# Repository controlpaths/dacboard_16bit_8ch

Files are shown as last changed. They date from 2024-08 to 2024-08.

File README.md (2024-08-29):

# 8CH DAC Board (16 bits)

Many times we need to obtain an analog signal from an embedded system. In these cases we will need a digital to analog converter. This board features two 4 channel digital to analog converters with a resolution of 16 bits. 

The output voltage of the board has a range from -10 volt to 10 volts qith a supply voltage of +-12V.

## Analog output

The DAC used in this board is the [DAC80004](https://www.ti.com/product/es-mx/DAC80004), a 4 channel, 16 bits DAC from Texas Instruments. This DAC is footprint compatible with DAC70004 (14 bits), and DAC60004 (12 bits).

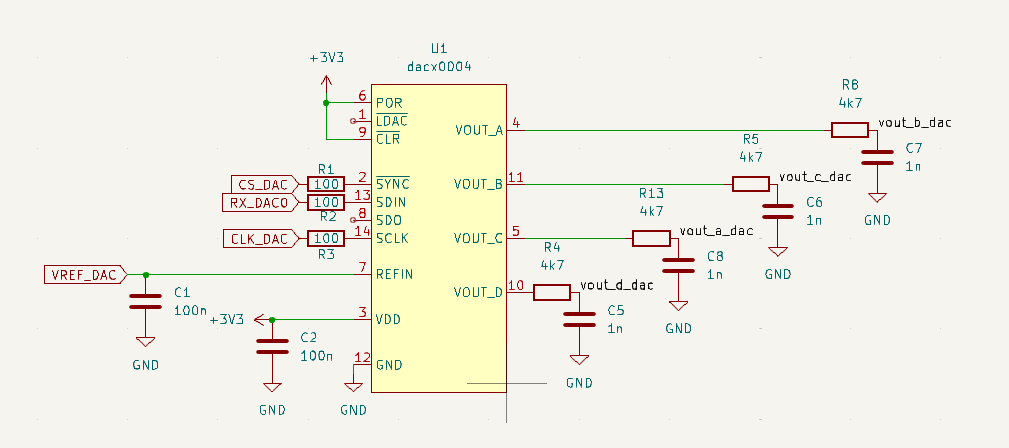
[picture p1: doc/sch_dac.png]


To obtain the bipolar output, a simple circuit with just one amplifier is used. 

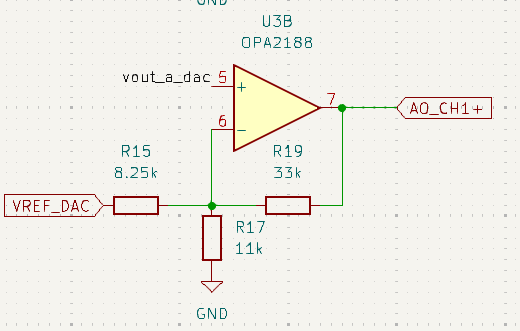
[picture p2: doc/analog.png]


## Voltage reference

For the output range of +-10V, we will need a voltage reference of 2.5 volts. We can reduce the output range, and therefore increase the resolution in volts by using a reference of 1.024 volts or 1.250.

The reference used is the REF5020 with soma capacitors for fixeliminate the noise in the output voltage.

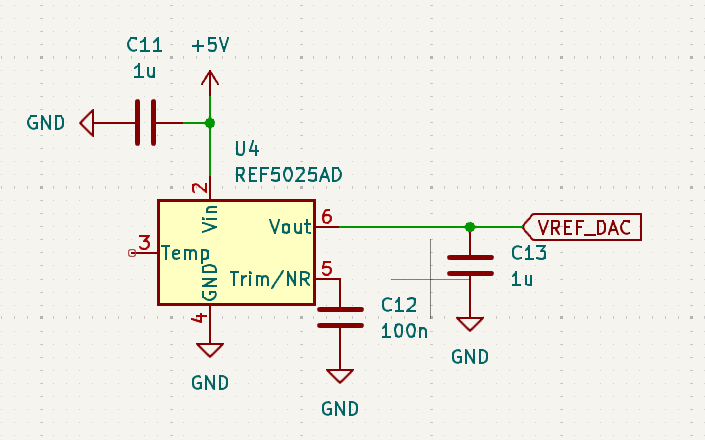
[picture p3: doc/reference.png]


## Connectors

The conenctor are the only component in the bottom side of the board. The board uses three connectors, one for the control of the DAC, and two for the output voltages.

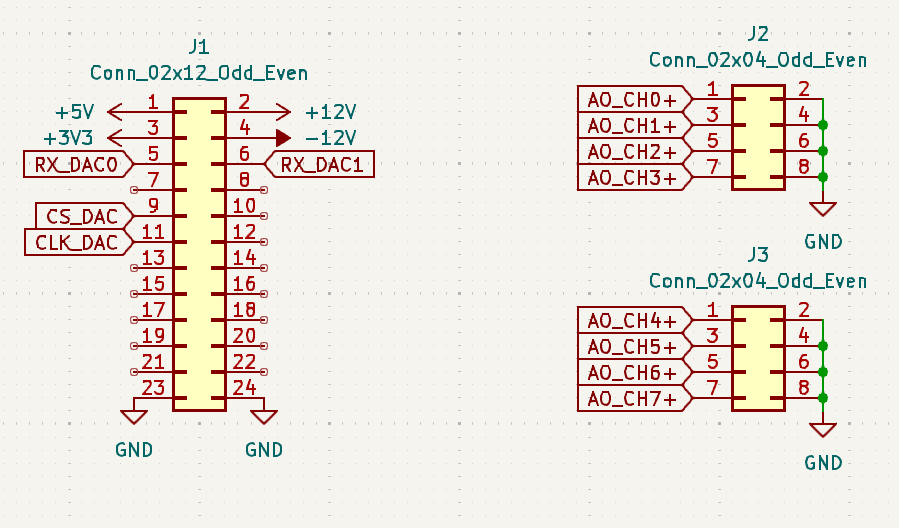
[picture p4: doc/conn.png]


## Layout

The layout of the board is 35mm x 50mm. Several VCC planes and GND planes are used in the board to share the power supplies.

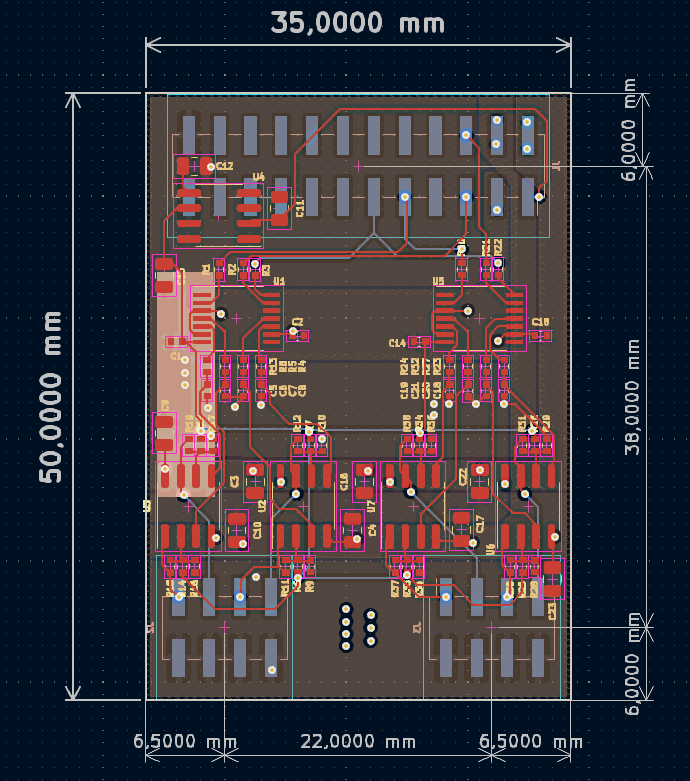
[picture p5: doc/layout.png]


## Get Yours

This DAC Board is open-source, so you can use the output files to build your own in [JLCPCB](https://jlcpcb.com/?from=controlpath). You just need to compress the `gerber` directory, and upload it to [JLCPCB](https://jlcpcb.com/?from=controlpath). 

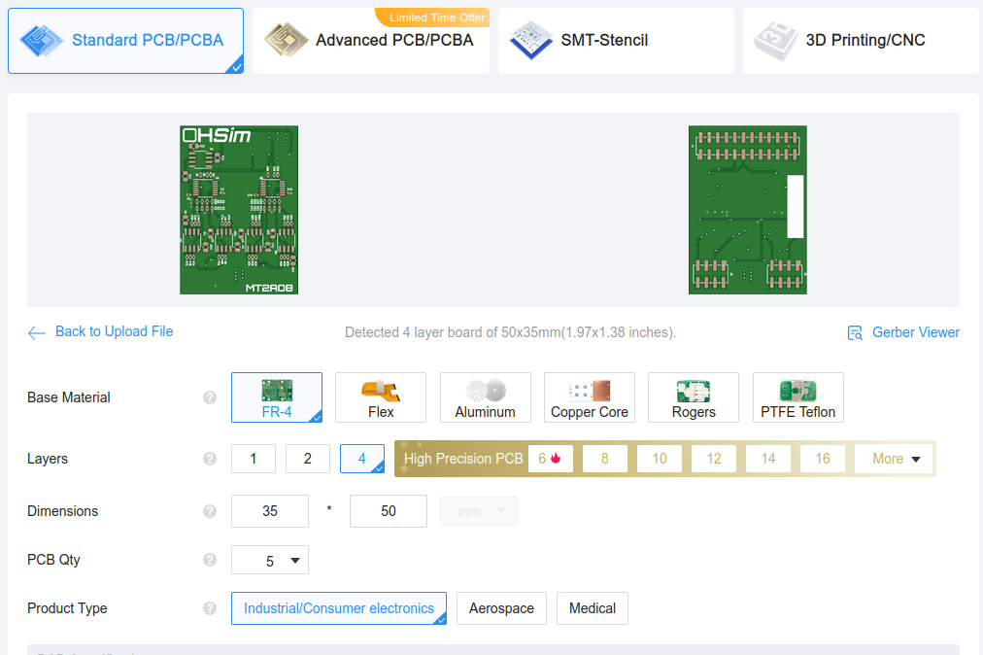
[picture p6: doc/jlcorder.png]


Remember to change the Surface Finish to **LeadFree HASL** to make your board ROHS compliant.

Then you have to add the PCB Assembly service and upload the [centroid](./kicad/production_files/dac16bit_8ch-all-pos.csv) file, and the [BOM](./kicad/production_files/bom.csv).

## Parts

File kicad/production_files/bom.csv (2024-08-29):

Designator | Comment | Footprint | JLCPCB Part #
C1,C2,C14,C15 | 100n | Capacitor_SMD:C_0402_1005Metric
C3,C4,C9,C10,C12,C16,C17,C22,C23 | 100n | Capacitor_SMD:C_0805_2012Metric
C5,C6,C7,C8,C18,C19,C20,C21 | 1n | Capacitor_SMD:C_0402_1005Metric
C11,C13 | 1u | Capacitor_SMD:C_0805_2012Metric
J1 | Conn_02x12_Odd_Even | Connector_PinHeader_2.54mm:PinHeader_2x12_P2.54mm_Vertical_SMD
J2,J3 | Conn_02x04_Odd_Even | Connector_PinHeader_2.54mm:PinHeader_2x04_P2.54mm_Vertical_SMD
R1,R2,R3,R20,R21,R22 | 100 | Resistor_SMD:R_0402_1005Metric
R4,R5,R8,R13,R23,R24,R27,R32 | 4k7 | Resistor_SMD:R_0402_1005Metric
R6,R7,R14,R15,R25,R26,R33,R34 | 8.25k | Resistor_SMD:R_0402_1005Metric
R9,R28 | 11k | Capacitor_SMD:C_0402_1005Metric
R10,R16,R17,R29,R35,R36 | 11k | Resistor_SMD:R_0402_1005Metric
R11,R12,R18,R19,R30,R31,R37,R38 | 33k | Resistor_SMD:R_0402_1005Metric
U1,U5 | dacx0004 | Package_SO:TSSOP-14_4.4x5mm_P0.65mm | C2679895
U2,U3,U6,U7 | OPA2188 | Package_SO:SOIC-8_3.9x4.9mm_P1.27mm | C17271
U4 | REF5025AD | Package_SO:SOIC-8_3.9x4.9mm_P1.27mm

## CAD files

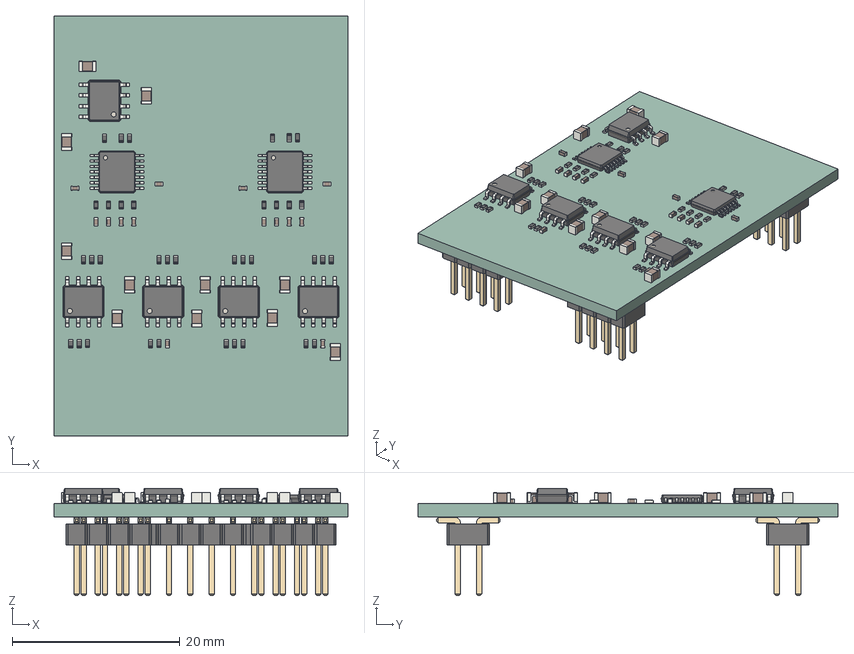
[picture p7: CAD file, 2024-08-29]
kicad/dac16bit_8ch.step
35.0 x 50.0 x 12.8 mm
C_0402_1005Metric x 14
R_0402_1005Metric x 36
C_0805_2012Metric x 11
SOIC_8_39x49mm_P127mm x 5
TSSOP_14_44x5mm_P065mm x 2
PinHeader_2x04_P254mm_Vertical_SMD x 2
PinHeader_2x12_P254mm_Vertical_SMD
MT2AO8_PCB

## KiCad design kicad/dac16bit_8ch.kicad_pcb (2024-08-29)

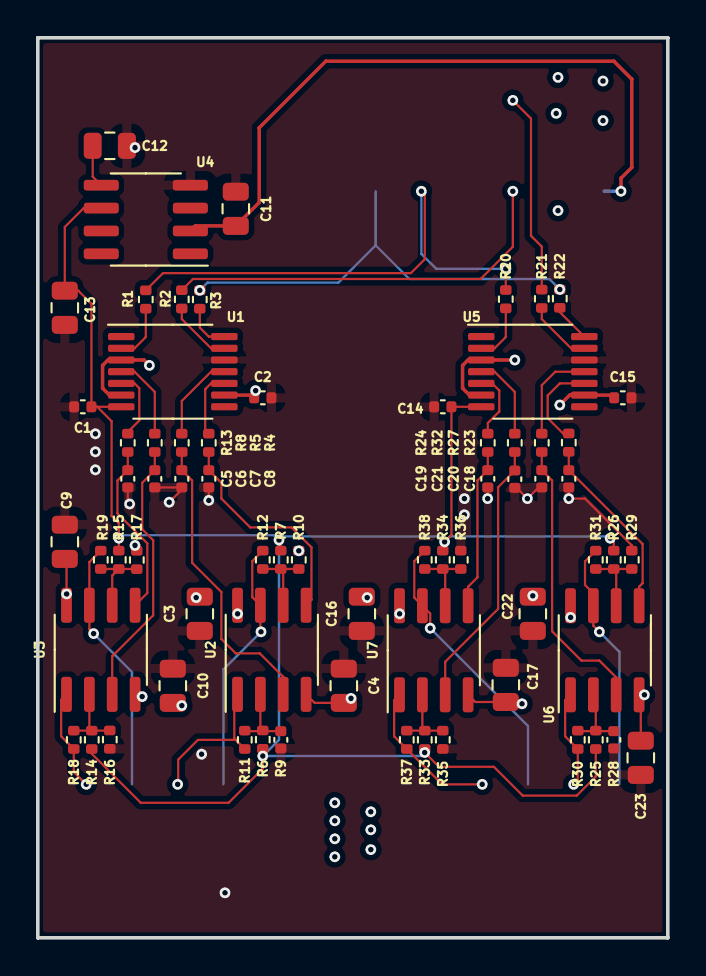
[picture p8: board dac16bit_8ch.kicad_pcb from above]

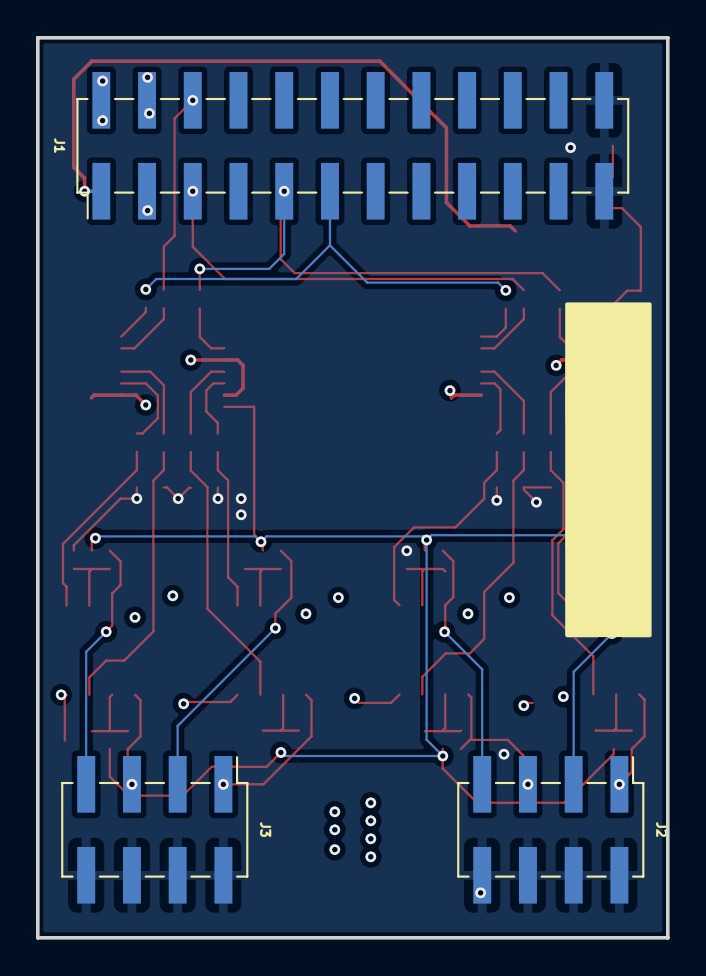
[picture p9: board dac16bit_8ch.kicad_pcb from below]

Board: 4 copper layers, 35.0 x 50.0 mm, 71 parts (3 on the bottom side), 49 nets.

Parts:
C1, C2, C14, C15: 100n; C_0402_1005Metric
C3, C4, C9, C10, C12, C16, C17, C22, C23: 100n; C_0805_2012Metric
C5, C6, C7, C8, C18, C19, C20, C21: 1n; C_0402_1005Metric
C11, C13: 1u; C_0805_2012Metric
J1: Conn_02x12_Odd_Even; PinHeader_2x12_P2.54mm_Vertical_SMD
J2, J3: Conn_02x04_Odd_Even; PinHeader_2x04_P2.54mm_Vertical_SMD
R1, R2, R3, R20, R21, R22: 100; R_0402_1005Metric
R4, R5, R8, R13, R23, R24, R27, R32: 4k7; R_0402_1005Metric
R6, R7, R14, R15, R25, R26, R33, R34: 8.25k; R_0402_1005Metric
R9, R28: 11k; C_0402_1005Metric
R10, R16, R17, R29, R35, R36: 11k; R_0402_1005Metric
R11, R12, R18, R19, R30, R31, R37, R38: 33k; R_0402_1005Metric
U1, U5: dacx0004; TSSOP-14_4.4x5mm_P0.65mm
U2, U3, U6, U7: OPA2188; SOIC-8_3.9x4.9mm_P1.27mm
U4: REF5025AD; SOIC-8_3.9x4.9mm_P1.27mm

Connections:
+3V3: C2.1, C15.1, J1.3, U1.3 (VDD), U1.6 (POR), U1.9 (~CLR), U5.3 (VDD), U5.6 (POR), U5.9 (~CLR)
+5V: C11.2, J1.1, U4.2 (Vin)
+12V: C3.2, C9.2, C16.2, C22.2, J1.2, U2.8 (V+), U3.8 (V+), U6.8 (V+), U7.8 (V+)
-12V: C4.2, C10.2, C17.2, C23.2, J1.4, U2.4 (V-), U3.4 (V-), U6.4 (V-), U7.4 (V-)
/dac0/vout_a_dac: C8.2, R13.2, U3.5 (+)
/dac0/vout_b_dac: C7.2, R8.2, U3.3 (+)
/dac0/vout_c_dac: C6.2, R5.2, U2.3 (+)
/dac0/vout_d_dac: C5.2, R4.2, U2.5 (+)
/dac1/vout_a_dac: C21.2, R32.2, U7.3 (+)
/dac1/vout_b_dac: C20.2, R27.2, U6.3 (+)
/dac1/vout_c_dac: C19.2, R24.2, U7.5 (+)
/dac1/vout_d_dac: C18.2, R23.2, U6.5 (+)
AO_CH0+: J2.1, R18.1, U3.1
AO_CH1+: J2.3, R19.1, U3.7
AO_CH2+: J2.5, R11.1, U2.1
AO_CH3+: J2.7, R12.1, U2.7
AO_CH4+: J3.1, R37.1, U7.1
AO_CH5+: J3.3, R38.1, U7.7
AO_CH6+: J3.5, R30.1, U6.1
AO_CH7+: J3.7, R31.1, U6.7
CLK_DAC: J1.11, R3.1, R22.1
CS_DAC: J1.9, R1.1, R20.1
GND: C1.2, C2.2, C3.1, C4.1, C5.1, C6.1, C7.1, C8.1, C9.1, C10.1, C11.1, C12.2, C13.2, C14.2, C15.2, C16.1, C17.1, C18.1, C19.1, C20.1, C21.1, C22.1, C23.1, J1.23, J1.24, J2.2, J2.4, J2.6, J2.8, J3.2, J3.4, J3.6, J3.8, R9.1, R10.1, R16.1, R17.1, R28.1, R29.1, R35.1, R36.1, U1.12 (GND), U4.4 (GND), U5.12 (GND)
unnamed: R3.2, U1.14 (SCLK)
unnamed: R2.2, U1.13 (SDIN)
unnamed: R8.1, U1.4 (VOUT_A)
unnamed: R5.1, U1.11 (VOUT_B)
unnamed: R13.1, U1.5 (VOUT_C)
unnamed: R4.1, U1.10 (VOUT_D)
unnamed: R1.2, U1.2 (~SYNC)
unnamed: R6.2, R9.2, R11.2, U2.2 (-)
unnamed: R7.2, R10.2, R12.2, U2.6 (-)
unnamed: R14.2, R16.2, R18.2, U3.2 (-)
unnamed: R15.2, R17.2, R19.2, U3.6 (-)
unnamed: C12.1, U4.5 (Trim/NR)
unnamed: R22.2, U5.14 (SCLK)
unnamed: R21.2, U5.13 (SDIN)
unnamed: R32.1, U5.4 (VOUT_A)
unnamed: R27.1, U5.11 (VOUT_B)
unnamed: R24.1, U5.5 (VOUT_C)
unnamed: R23.1, U5.10 (VOUT_D)
unnamed: R20.2, U5.2 (~SYNC)
unnamed: R25.2, R28.2, R30.2, U6.2 (-)
unnamed: R26.2, R29.2, R31.2, U6.6 (-)
unnamed: R33.2, R35.2, R37.2, U7.2 (-)
unnamed: R34.2, R36.2, R38.2, U7.6 (-)
RX_DAC0: J1.5, R2.1
RX_DAC1: J1.6, R21.1
VREF_DAC: C1.1, C13.1, C14.1, R6.1, R7.1, R14.1, R15.1, R25.1, R26.1, R33.1, R34.1, U1.7 (REFIN), U4.6 (Vout), U5.7 (REFIN)
